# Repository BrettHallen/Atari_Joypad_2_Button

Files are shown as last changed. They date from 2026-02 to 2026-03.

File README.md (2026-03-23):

# Atari Joypad (Two Button) aka Brett's Clueless Joypad
Simple two-button joypad using Atari pinout, compatible with both Atari 2600 & Atari 7800.<br>

Its purpose is for use as a small "troubleshooting" joypad when you are trying to repair a vintage computer and you have its bare motherboard on the bench.<br>

It has no higher aspirations than that.<br>

It is no larger than 100mm so its fabrication falls under the cheapest PCB cost (i.e. ten PCBs for US$5 at PCBWAY).<br>

There are three [right handed](/RightHanded) versions:<br>
- Rev. A matches the Atari 7800 layout: FIRE1 on left, FIRE2 on right
- Rev. B matches the NES layout: FIRE1/A on right, FIRE2/B on left
- Rev. C where FIRE1/FIRE2 position is selectable via solder bridge (default is Rev. A layout)

In testing I found my right thumb naturally resting on the FIRE2 (rightmost) button, hence the Rev. B design.  The Rev. C design has them selectable via solder bridge (thanks to suggestion by SheldonHarold/YouTube).<br>

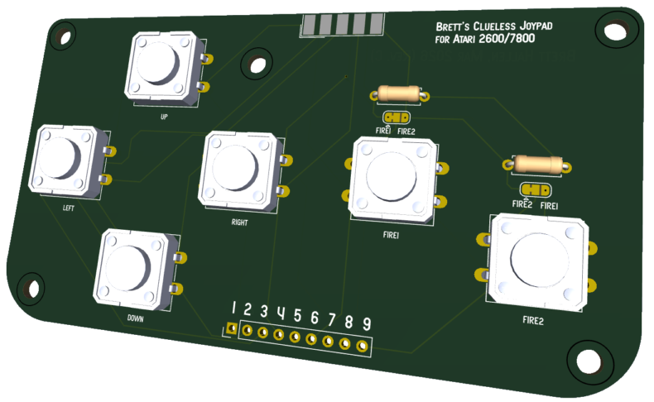
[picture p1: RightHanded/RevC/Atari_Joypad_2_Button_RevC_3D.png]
Clueless Joypad RH Rev. C


Of course using it with something that expects Atari 2600 it doesn't matter as both FIRE buttons function the same.<br>

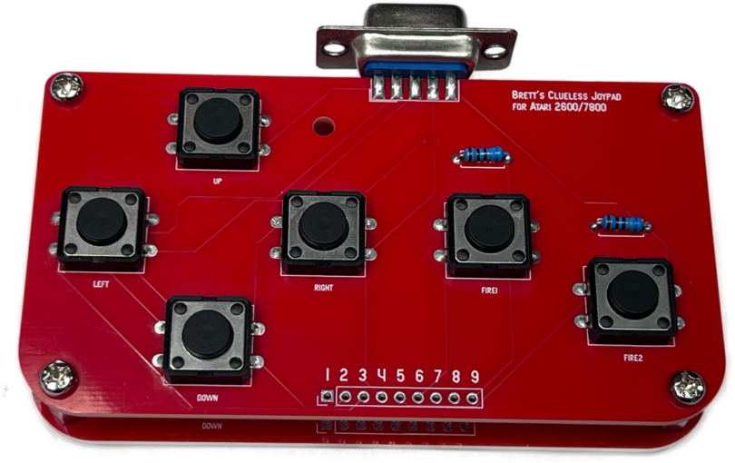
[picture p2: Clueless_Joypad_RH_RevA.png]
Clueless Joypad RH Rev. C


I have started a [left-handed](/LeftHanded) version ... any need?

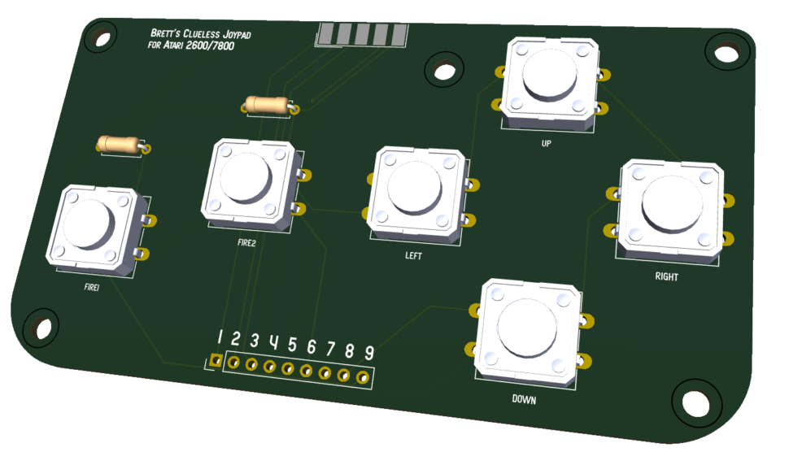
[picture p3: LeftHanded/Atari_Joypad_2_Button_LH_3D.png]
Clueless Joypad LH 3D


## YouTube Videos
- [Part 1: Initial test (right handed, Rev. A)](https://youtu.be/WF11pfEDQUY)

## [Paddle](/Paddle)
Design for a troubleshooting paddle based on Atari design (thanks to suggestion by Ascania/YouTube).<br>

Suggested linear potentiometer values I've seen are 1MΩ for Atari and 470KΩ for Commodore.<br>

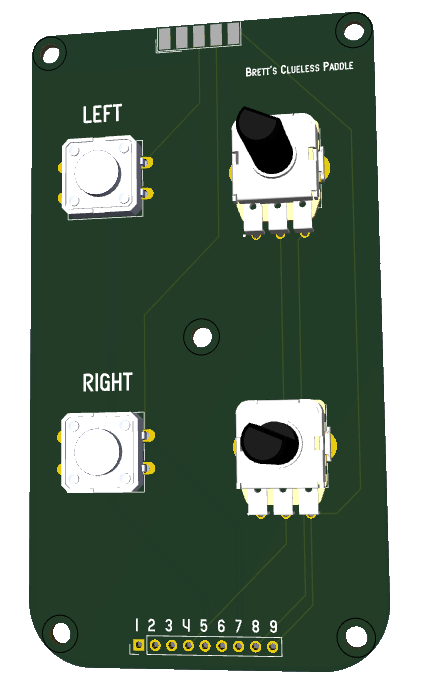
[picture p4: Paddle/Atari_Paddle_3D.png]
Paddle 3D


## [MSX Adaptor](/MSX_Adaptor)
I had an idea that an MSX adaptor board could be connected underneath the Atari 2600/7800 board.<br>

The one joypad could then be connected natively to either Atari 2600/7800 (top PCB) or MSX (bottom PCB).<br>

??<br>

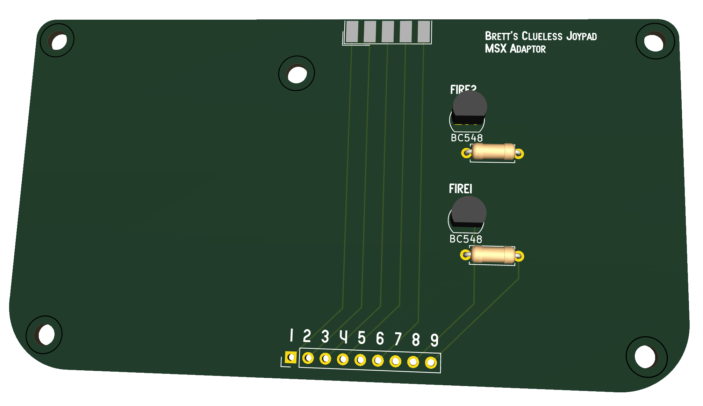
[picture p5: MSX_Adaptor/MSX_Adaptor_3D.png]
MSX adaptor 3D


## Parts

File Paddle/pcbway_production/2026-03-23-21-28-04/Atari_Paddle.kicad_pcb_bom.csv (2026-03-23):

Designator | Quantity | Value | Footprint | Package | MPN | DNP | Mount_Type | Description | Height | Mouser Part Number | Mouser Price/Stock | Manufacturer_Name
J1 | 1 | DE9 Female | DSUB-9_Socket_EdgeMount_P2.77mm |  |  |  | smt | 9-pin D-SUB connector, socket (female)
J2 | 1 | Pin Header | PinHeader_1x09_P2.54mm_Vertical |  |  |  | tht | Generic connector, single row, 01x09, script generated (kicad-library-utils/schlib/autogen/connector/)
SW1 | 1 | LEFT | SW_PUSH-12mm |  |  |  | tht | Push button switch, normally open, two pins, 45° tilted
SW2 | 1 | RIGHT | SW_PUSH-12mm |  |  |  | tht | Push button switch, normally open, two pins, 45° tilted
VR1, VR2 | 2 | PDB12-M4251-105BF | PDB12M4251105BF |  | PDB12-M4251-105BF |  | tht | Potentiometers 1M LINEAR 12MM | 25 | 652-PDB12-M4251105BF | https://www.mouser.co.uk/ProductDetail/Bourns/PDB12-M4251-105BF?qs=8Ua%252BV%252BmvZK4cUDj2fkbDjA%3D%3D | Bourns

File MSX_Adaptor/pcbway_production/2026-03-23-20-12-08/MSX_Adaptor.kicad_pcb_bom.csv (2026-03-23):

Designator | Quantity | Value | Footprint | Package | MPN | DNP | Mount_Type | Description | Sim.Device | Sim.Type | Sim.Pins
J1 | 1 | MSX Output | DSUB-9_Socket_EdgeMount_P2.77mm |  |  |  | smt | 9-pin D-SUB connector, socket (female)
J2 | 1 | Atari Input | PinHeader_1x09_P2.54mm_Vertical |  |  |  | tht | Generic connector, single row, 01x09, script generated (kicad-library-utils/schlib/autogen/connector/)
Q1, Q2 | 2 | BC548 | TO-92_Inline |  |  |  | tht | Bipolar transistor symbol for simulation only, substrate tied to the emitter | NPN | GUMMELPOON | 1=C 2=B 3=E
R1, R2 | 2 | 10KΩ | R_Axial_DIN0207_L6.3mm_D2.5mm_P7.62mm_Horizontal |  |  |  | tht | Resistor

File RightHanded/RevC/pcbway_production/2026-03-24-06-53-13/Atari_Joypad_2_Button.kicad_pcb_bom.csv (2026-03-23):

Designator | Quantity | Value | Footprint | Package | MPN | DNP | Mount_Type | Description
J1 | 1 | DE9 Female | DSUB-9_Socket_EdgeMount_P2.77mm |  |  |  | smt | 9-pin D-SUB connector, socket (female)
J2 | 1 | Pin Header | PinHeader_1x09_P2.54mm_Vertical |  |  |  | tht | Generic connector, single row, 01x09, script generated (kicad-library-utils/schlib/autogen/connector/)
R1, R2 | 2 | 620Ω | R_Axial_DIN0207_L6.3mm_D2.5mm_P7.62mm_Horizontal |  |  |  | tht | Resistor
SW1 | 1 | UP | SW_PUSH-12mm |  |  |  | tht | Push button switch, normally open, two pins, 45° tilted
SW2 | 1 | DOWN | SW_PUSH-12mm |  |  |  | tht | Push button switch, normally open, two pins, 45° tilted
SW3 | 1 | LEFT | SW_PUSH-12mm |  |  |  | tht | Push button switch, normally open, two pins, 45° tilted
SW4 | 1 | RIGHT | SW_PUSH-12mm |  |  |  | tht | Push button switch, normally open, two pins, 45° tilted
SW5, SW6 | 2 | FIRE | SW_PUSH-12mm |  |  |  | tht | Push button switch, normally open, two pins, 45° tilted

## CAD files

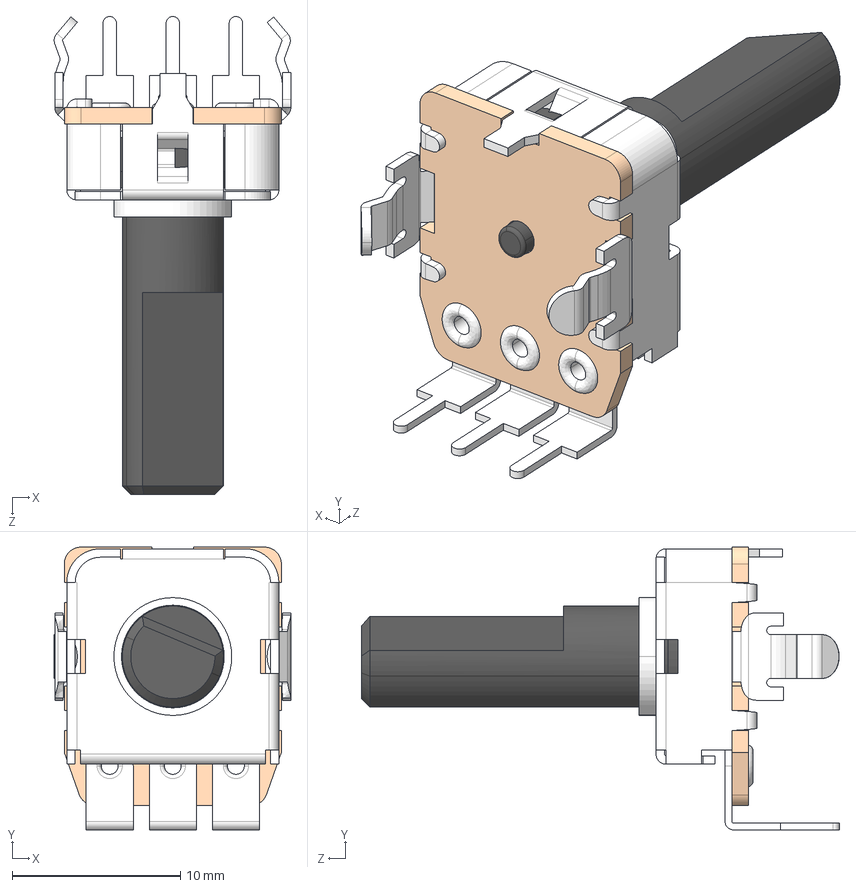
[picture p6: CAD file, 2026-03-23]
Paddle/LIB_PDB12-M4251-105BF/PDB12-M4251-105BF/3D/PDB12-M4251-105BF.stp
14.1 x 16.8 x 28.4 mm
外壳
轴心
端子 x 3
电阻片

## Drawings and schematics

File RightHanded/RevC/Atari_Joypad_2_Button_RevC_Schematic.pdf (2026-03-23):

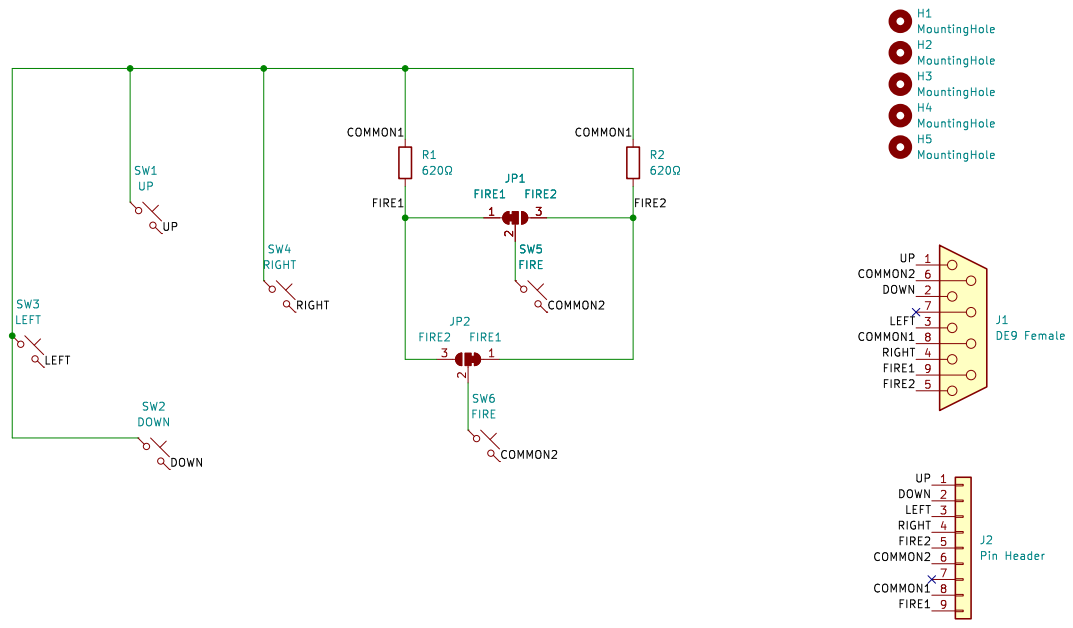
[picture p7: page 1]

H3 MountingHole H2 MountingHole H1 MountingHole H4 MountingHole

Id: 1/1 Title: Brett's Silly Little Joypad Design

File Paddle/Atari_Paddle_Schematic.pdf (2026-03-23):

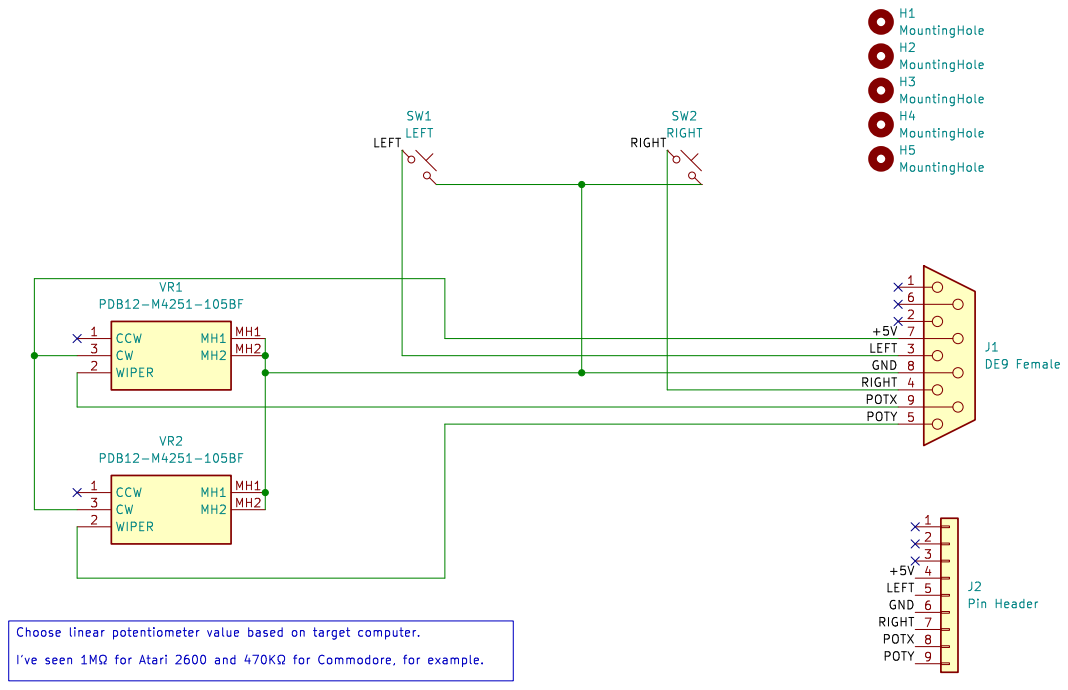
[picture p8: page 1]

Id: 1/1 Title: Brett's Stupid Little Paddle Design

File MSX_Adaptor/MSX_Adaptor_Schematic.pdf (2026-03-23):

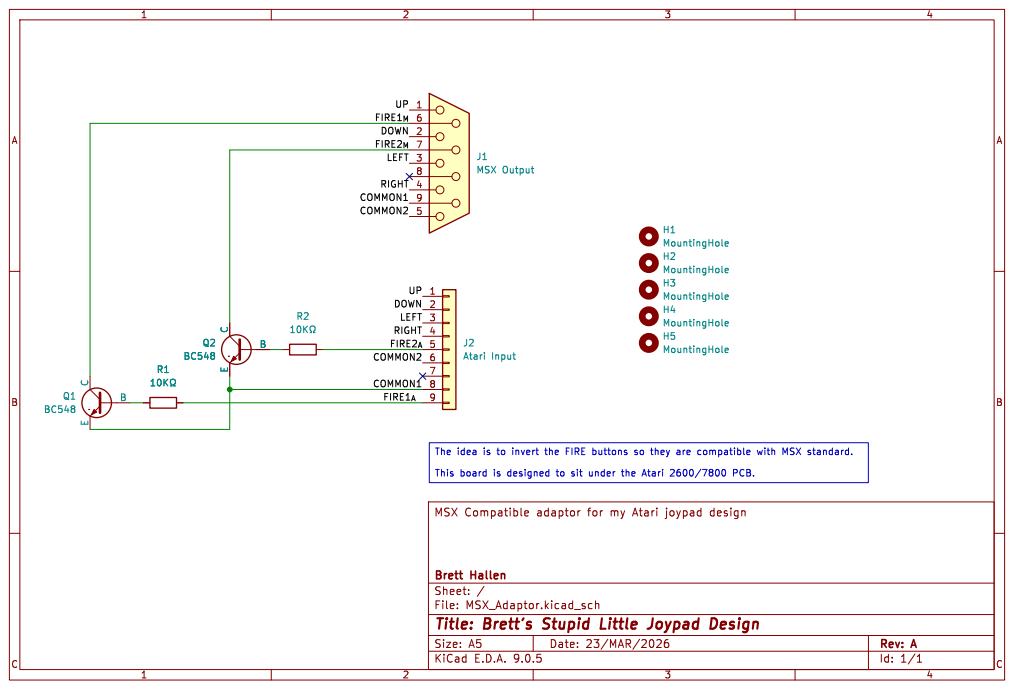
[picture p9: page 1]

Sheet: /
Title: Brett's Stupid Little Joypad Design

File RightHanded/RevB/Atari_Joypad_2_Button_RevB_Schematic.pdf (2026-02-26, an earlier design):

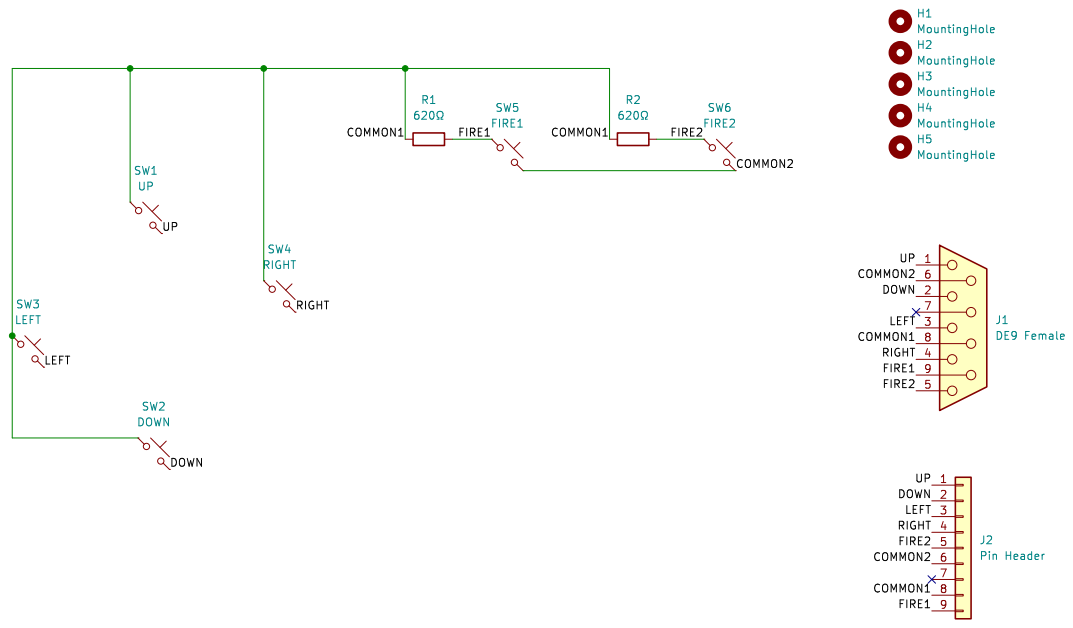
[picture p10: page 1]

Id: 1/1 Title: Brett's Stupid Little Joypad Design

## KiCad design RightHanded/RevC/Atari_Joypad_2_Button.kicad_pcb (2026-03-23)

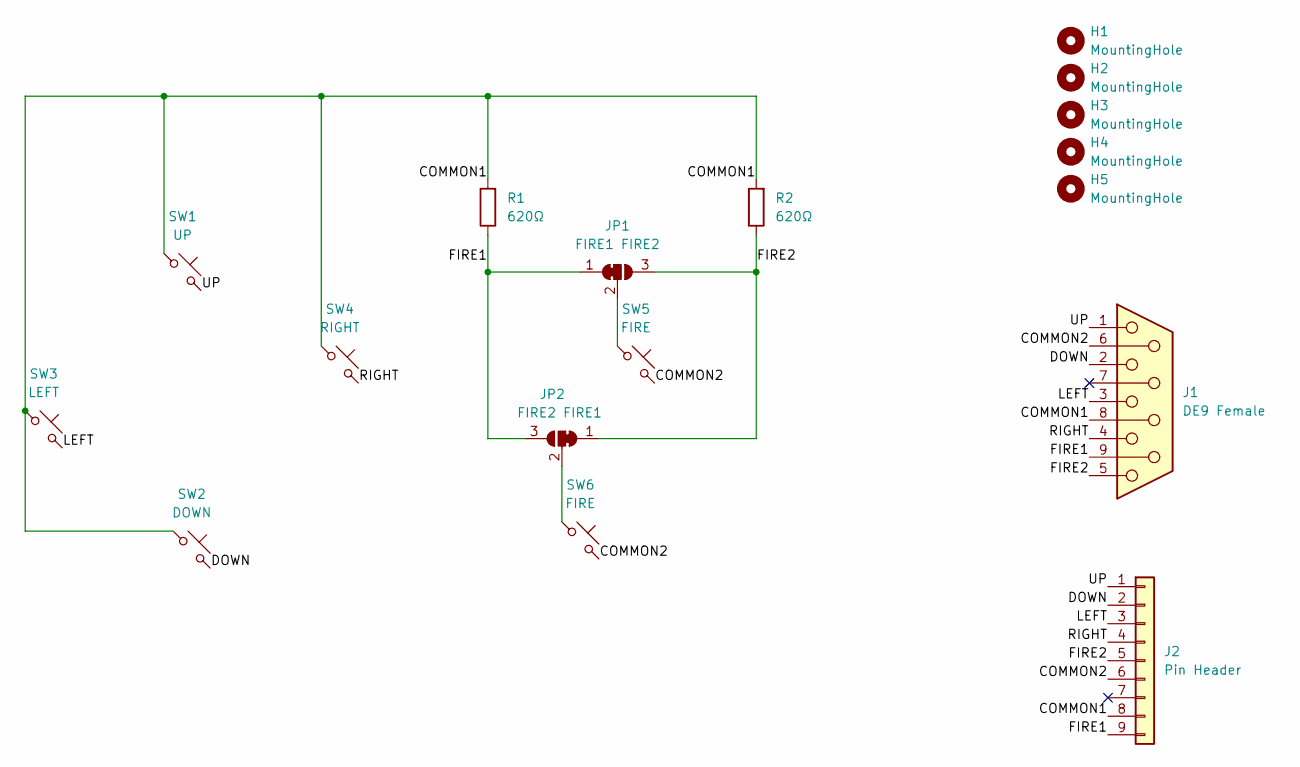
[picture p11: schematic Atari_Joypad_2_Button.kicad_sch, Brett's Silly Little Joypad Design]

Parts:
H1, H2, H3, H4, H5: MountingHole; MountingHole_3.2mm_M3_DIN965
J1: DE9 Female; DSUB-9_Socket_EdgeMount_P2.77mm
J2: Pin Header; PinHeader_1x09_P2.54mm_Vertical
JP1: FIRE1 FIRE2; SolderJumper-3_P1.3mm_Bridged12_RoundedPad1.0x1.5mm
JP2: FIRE2 FIRE1; SolderJumper-3_P1.3mm_Bridged12_RoundedPad1.0x1.5mm
R1, R2: 620Ω; R_Axial_DIN0207_L6.3mm_D2.5mm_P7.62mm_Horizontal
SW1: UP; SW_PUSH-12mm
SW2: DOWN; SW_PUSH-12mm
SW3: LEFT; SW_PUSH-12mm
SW4: RIGHT; SW_PUSH-12mm
SW5, SW6: FIRE; SW_PUSH-12mm

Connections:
/COMMON1: J1.8, J2.8, R1.2, R2.2, SW1.1, SW2.1, SW3.1, SW4.1
/COMMON2: J1.6, J2.6, SW5.2, SW6.2
/DOWN: J1.2, J2.2, SW2.2
/FIRE1: J1.9, J2.9, JP1.1 (A), JP2.3 (B), R1.1
/FIRE2: J1.5, J2.5, JP1.3 (B), JP2.1 (A), R2.1
/LEFT: J1.3, J2.3, SW3.2
/RIGHT: J1.4, J2.4, SW4.2
/UP: J1.1, J2.1, SW1.2
unnamed: JP1.2 (C), SW5.1
unnamed: JP2.2 (C), SW6.1

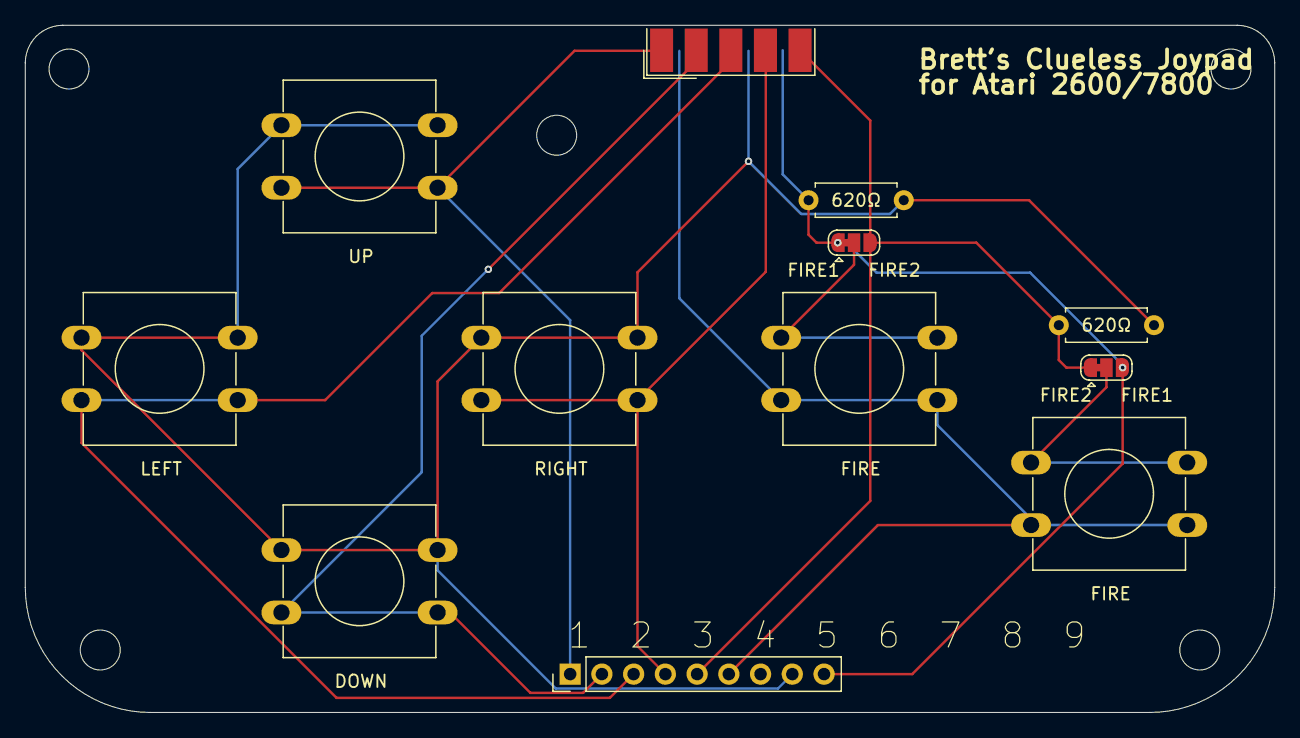
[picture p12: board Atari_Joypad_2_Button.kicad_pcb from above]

Board: 2 copper layers, 100.0 x 55.0 mm, 17 parts (0 on the bottom side), 10 nets.

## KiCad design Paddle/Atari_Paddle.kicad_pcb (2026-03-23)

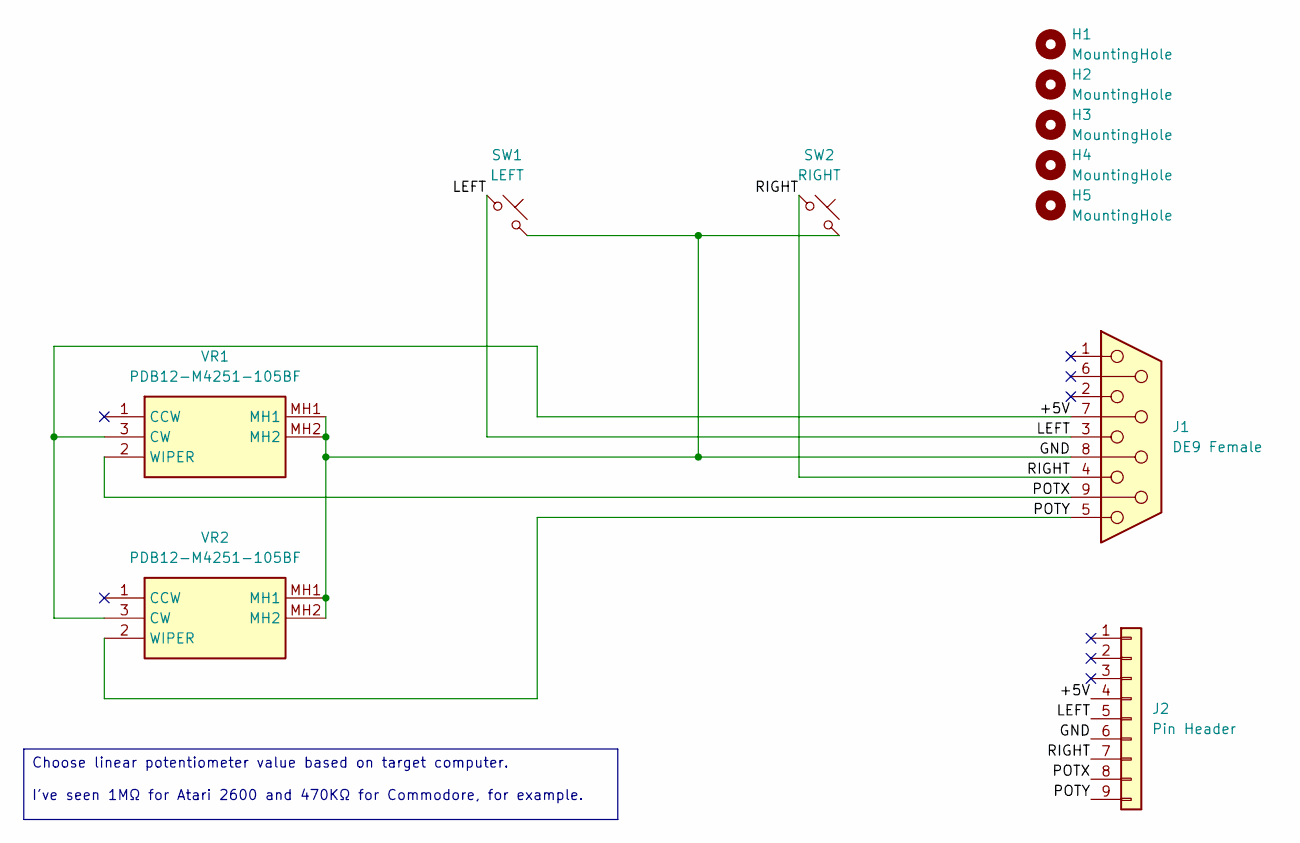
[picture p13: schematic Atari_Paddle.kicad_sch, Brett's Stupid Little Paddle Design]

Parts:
H1, H2, H3, H4, H5: MountingHole; MountingHole_3.2mm_M3_DIN965
J1: DE9 Female; DSUB-9_Socket_EdgeMount_P2.77mm
J2: Pin Header; PinHeader_1x09_P2.54mm_Vertical
SW1: LEFT; SW_PUSH-12mm
SW2: RIGHT; SW_PUSH-12mm
VR1, VR2: PDB12-M4251-105BF; PDB12M4251105BF; Mouser Part Number 652-PDB12-M4251105BF

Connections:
/+5V: J1.7, J2.4, VR1.3 (CW), VR2.3 (CW)
/GND: J1.8, J2.6, SW1.2, SW2.2, VR1.MH1, VR1.MH2, VR2.MH1, VR2.MH2
/LEFT: J1.3, J2.5, SW1.1
/POTX: J1.9, J2.8, VR1.2 (WIPER)
/POTY: J1.5, J2.9, VR2.2 (WIPER)
/RIGHT: J1.4, J2.7, SW2.1

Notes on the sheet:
Choose linear potentiometer value based on target computer. I've seen 1MΩ for Atari 2600 and 470KΩ for Commodore, for example.

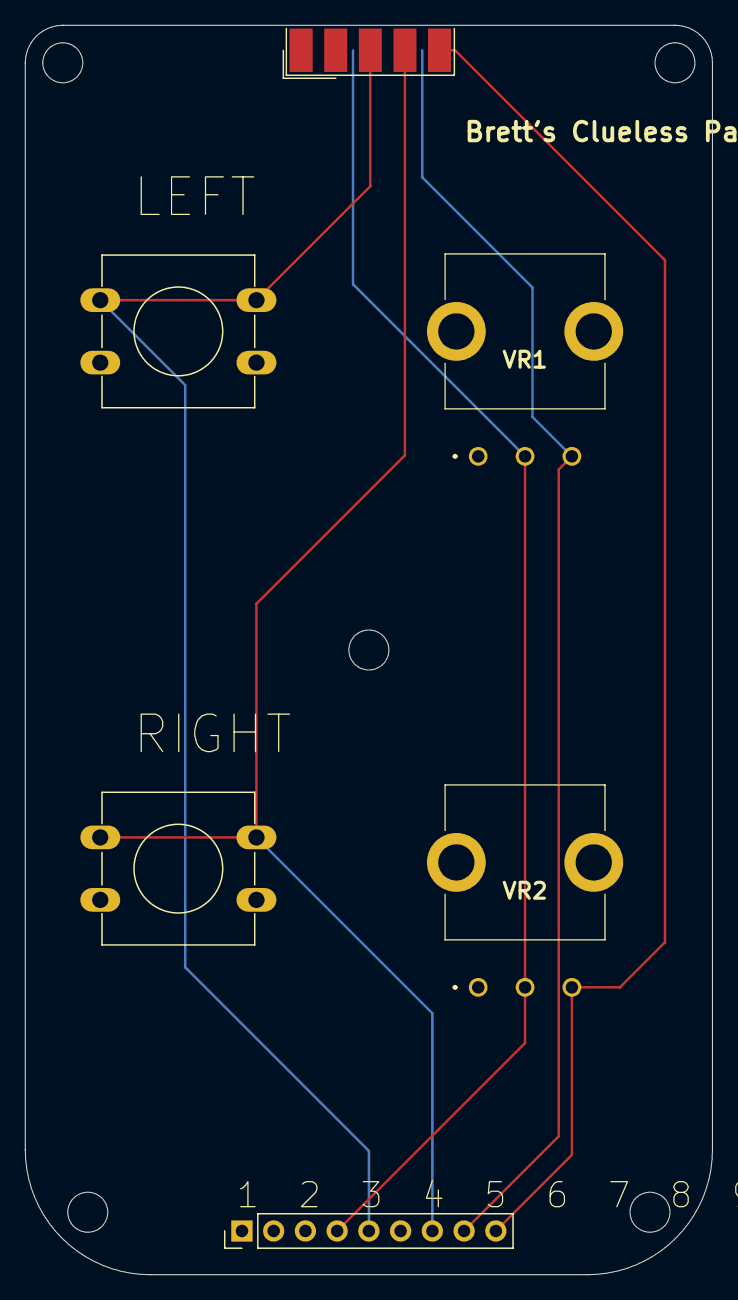
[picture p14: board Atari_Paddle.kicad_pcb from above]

Board: 2 copper layers, 55.0 x 100.0 mm, 11 parts (0 on the bottom side), 6 nets.

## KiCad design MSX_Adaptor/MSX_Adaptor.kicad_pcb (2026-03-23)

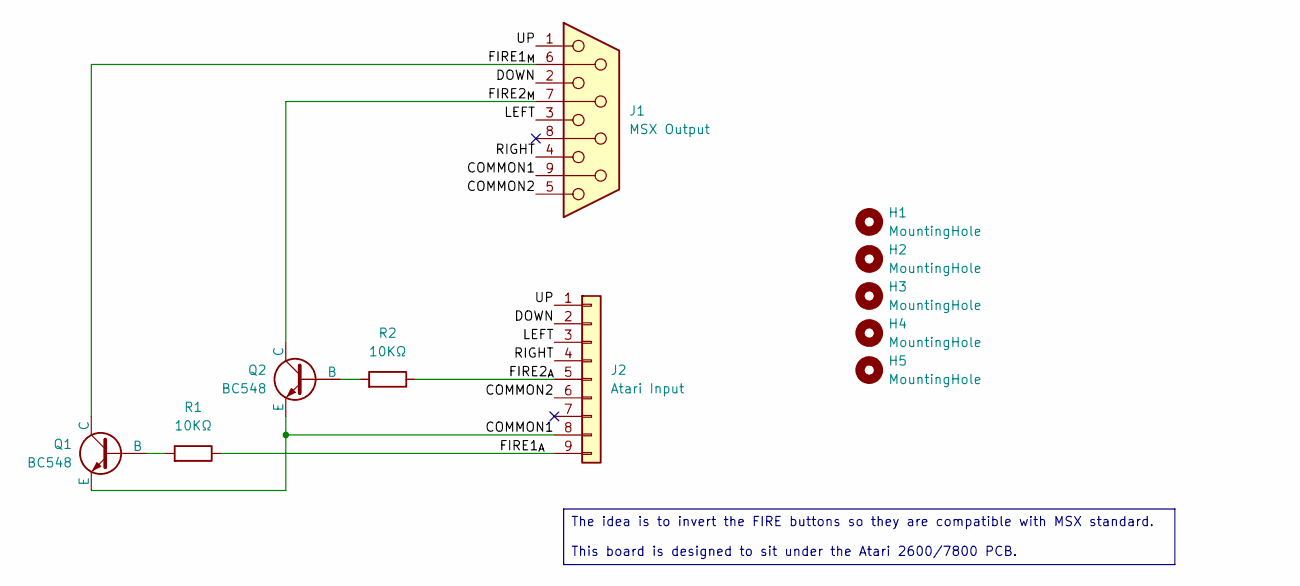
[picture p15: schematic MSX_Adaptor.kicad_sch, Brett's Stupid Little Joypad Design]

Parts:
H1, H2, H3, H4, H5: MountingHole; MountingHole_3.2mm_M3_DIN965
J1: MSX Output; DSUB-9_Socket_EdgeMount_P2.77mm
J2: Atari Input; PinHeader_1x09_P2.54mm_Vertical
Q1, Q2: BC548; TO-92_Inline
R1, R2: 10KΩ; R_Axial_DIN0207_L6.3mm_D2.5mm_P7.62mm_Horizontal

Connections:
/COMMON1: J1.9, J2.8, Q1.3 (E), Q2.3 (E)
/COMMON2: J1.5, J2.6
/DOWN: J1.2, J2.2
/FIRE1_{A}: J2.9, R1.1
/FIRE1_{M}: J1.6, Q1.1 (C)
/FIRE2_{A}: J2.5, R2.1
/FIRE2_{M}: J1.7, Q2.1 (C)
/LEFT: J1.3, J2.3
/RIGHT: J1.4, J2.4
/UP: J1.1, J2.1
unnamed: Q1.2 (B), R1.2
unnamed: Q2.2 (B), R2.2

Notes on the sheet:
The idea is to invert the FIRE buttons so they are compatible with MSX standard. This board is designed to sit under the Atari 2600/7800 PCB.

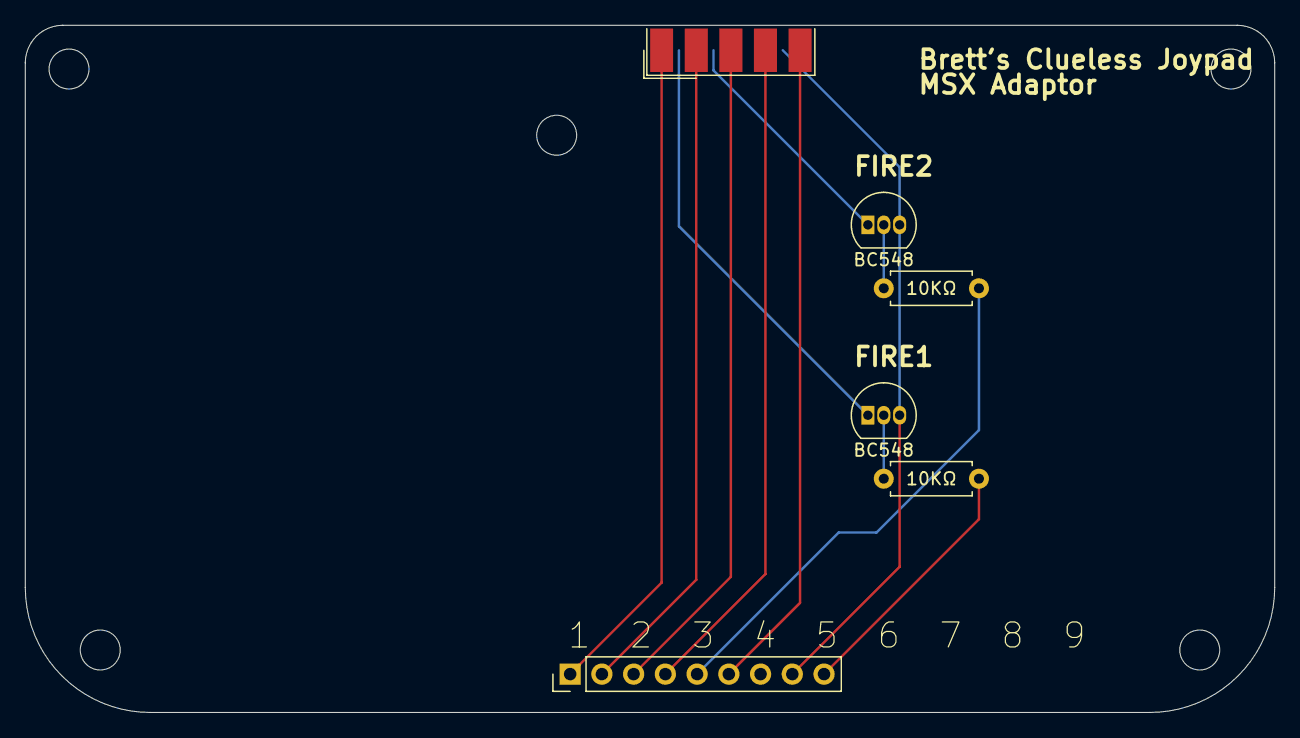
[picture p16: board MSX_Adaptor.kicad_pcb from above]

Board: 2 copper layers, 100.0 x 55.0 mm, 11 parts (0 on the bottom side), 12 nets.

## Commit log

2026-03-23 Moved to Rev. A folder
    [Atari_Joypad_2_Button.kicad_pcb, Atari_Joypad_2_Button.kicad_pcb_bom.csv, Atari_Joypad_2_Button.kicad_pcb_positions.csv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]
2026-03-23 Swapped FIRE1 & FIRE2 positions (matches NES Joypad)
    [Atari_Joypad_2_Button.kicad_pcb, Atari_Joypad_2_Button.kicad_pcb_bom.csv, Atari_Joypad_2_Button.kicad_pcb_positions.csv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]
2026-03-23 Initial left-handed design
    [Atari_Joypad_2_Button.kicad_pcb, Atari_Joypad_2_Button.kicad_sch]
2026-03-23 Idea for an MSX adaptor
    [MSX_Adaptor.kicad_pcb, MSX_Adaptor.kicad_pcb_bom.csv, MSX_Adaptor.kicad_pcb_positions.csv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]
2026-03-23 Possible paddle design
    [Atari_Paddle.kicad_pcb, Atari_Paddle.kicad_pcb_bom.csv, Atari_Paddle.kicad_pcb_positions.csv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]
2026-03-23 Added Rev C with selectable FIRE1/FIRE2 position
    [Atari_Joypad_2_Button.kicad_pcb, Atari_Joypad_2_Button.kicad_pcb_bom.csv, Atari_Joypad_2_Button.kicad_pcb_positions.csv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]
2026-03-23 Atari-like font used on PCBs
